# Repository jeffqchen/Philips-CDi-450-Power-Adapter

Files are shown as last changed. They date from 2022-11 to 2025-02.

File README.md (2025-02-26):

# Philips CD-i 450/550 Power Adapter

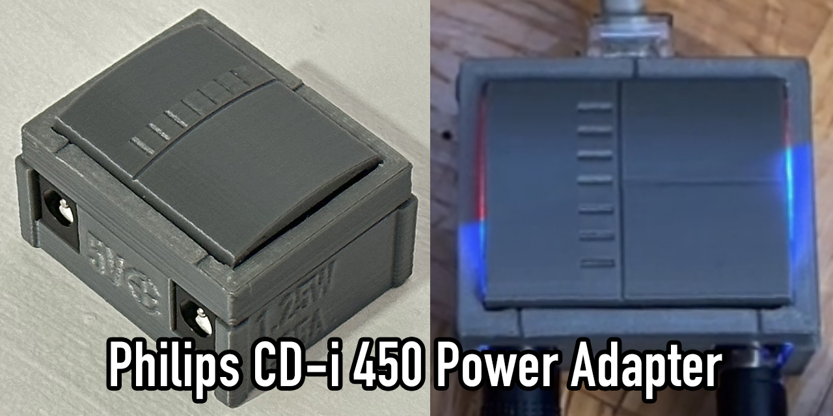
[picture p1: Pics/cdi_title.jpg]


------
## Update: Alternative Solution You Can Buy - G2 PSU



Zaxour designed a new replacement power supply that takes a single power input and converts it to all the necessary power rails. I had the honor to design a shell for it.

You can actually purchase the G2 PSU [here](https://ko-fi.com/s/8996431f0d).

------
## Rambling

The Philips CD-i 450/550 has a weird PSU (Type 20 PS 301/XX, 20PS301, 22ER9156). It uses an RJ45 jack to connect to the console.

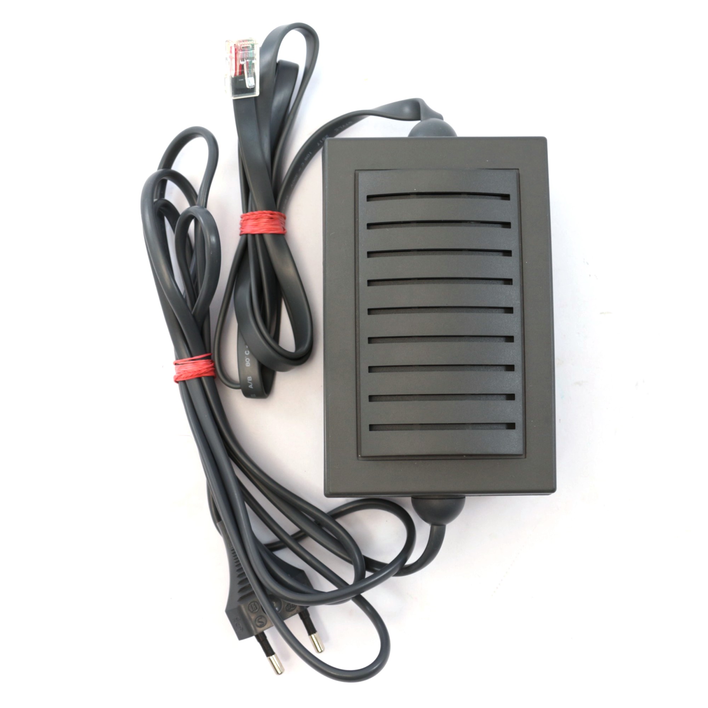
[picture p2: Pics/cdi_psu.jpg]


Everybody familiar with ethernet cables knows the plastic tab on an RJ45 plug will snap off sooner or later. Then the plug will become loose and start falling out of the jack. While it might not be that devastating on a network connection, it is unacceptable for a power connection. Not to mention that over the decades, some consoles were separated from their original PSU, and replacements are expensive while supplies being limited.

------
## Functionality

### Power Sources

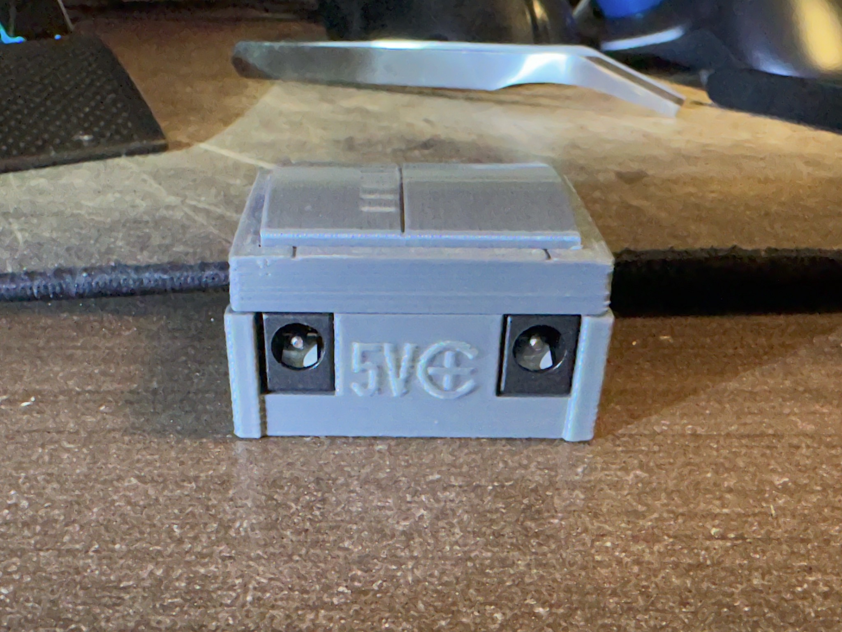
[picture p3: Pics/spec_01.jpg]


This adapter utilizes TWO **Center-Positive 5V** power adapters, with the plug dimension of **5.50mm OD (0.217") and 2.10mm ID (0.083")**.

**Do NOT** use a Y-adapter with a single power source or your adapter will short and die.

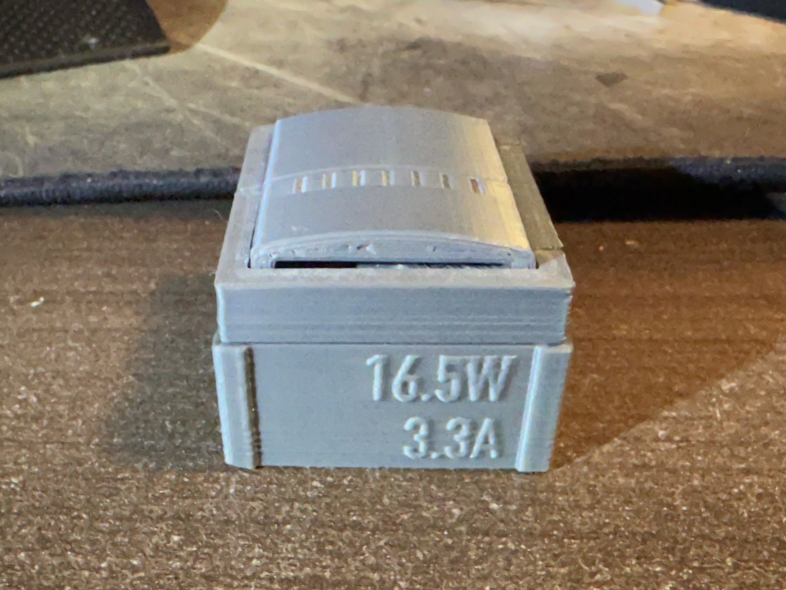
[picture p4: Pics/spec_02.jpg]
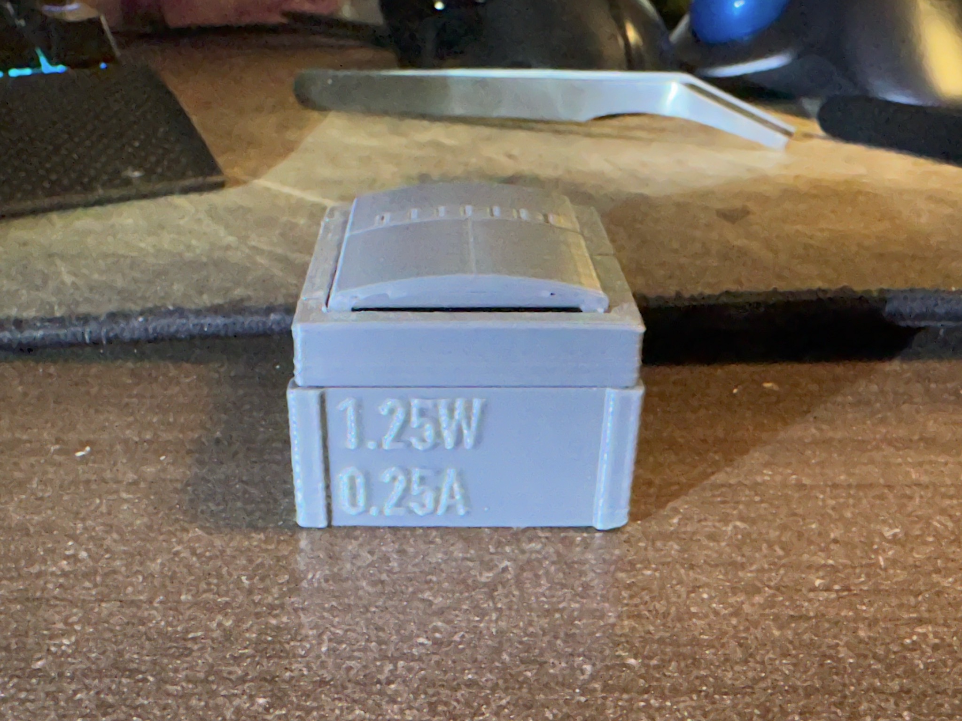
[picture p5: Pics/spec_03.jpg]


The one on the left requires 3.3A (16.5W). I call this the "beefy" one.

The one on the right is a weak one that any 5V adapter you can find will be more than capable to handle the job.

These power rating specs are the lowest requirements. You can go higher but not lower.

### Transmission Cable

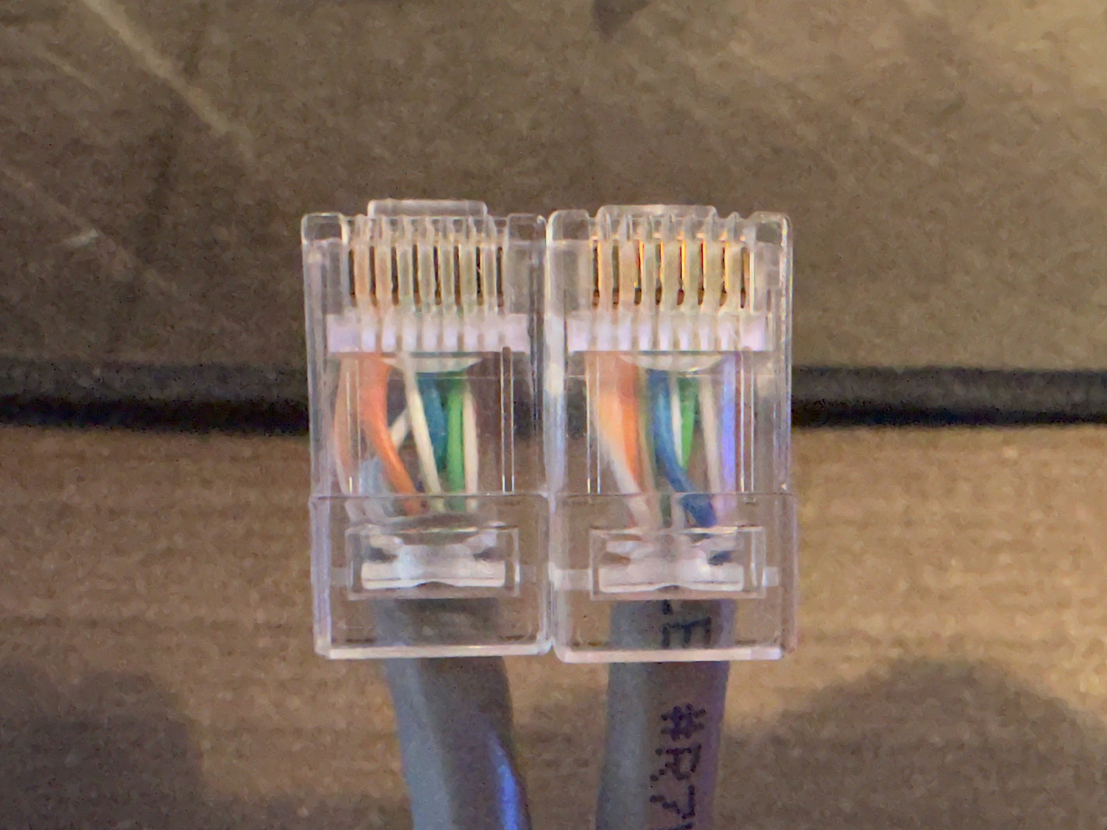
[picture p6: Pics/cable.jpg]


Use a **straight** RJ45 ethernet cable in short length. The wiring order on the two ends of the cable should be **exactly the same** or bad things will happen. It's easy to test with a meter if visual inspection is difficult.

### Usage

Plug everything in and use the power switch on the CD-i itself to turn the power on/off.

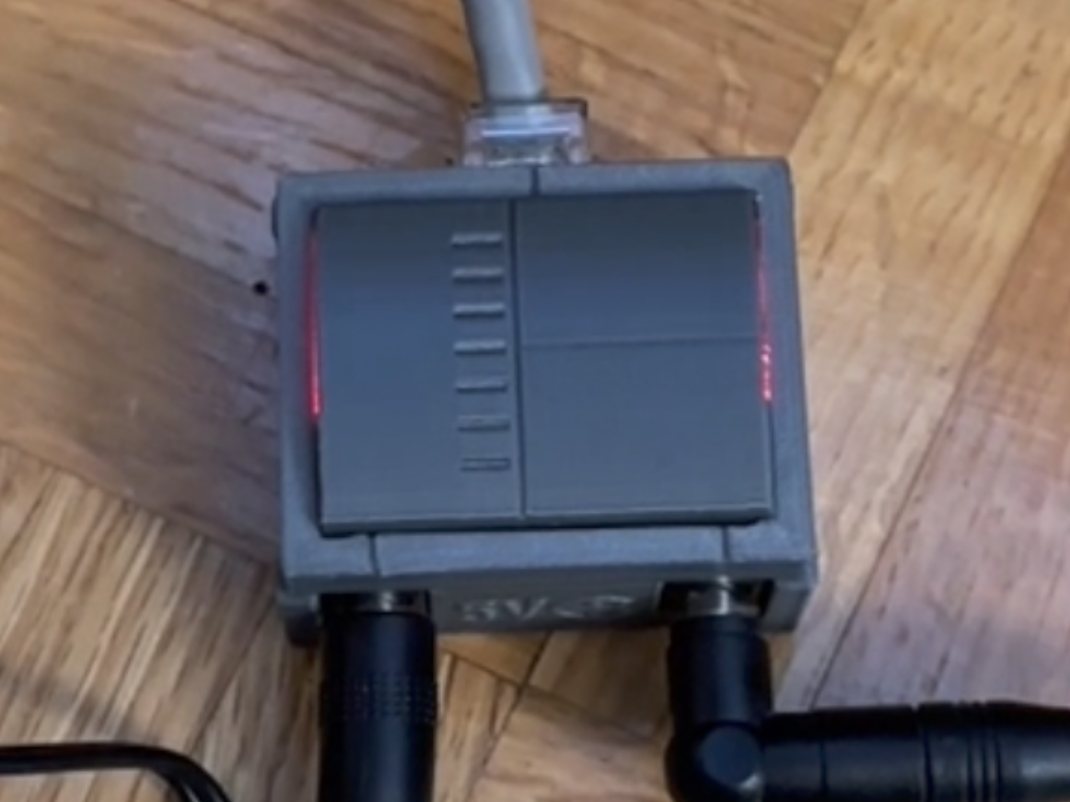
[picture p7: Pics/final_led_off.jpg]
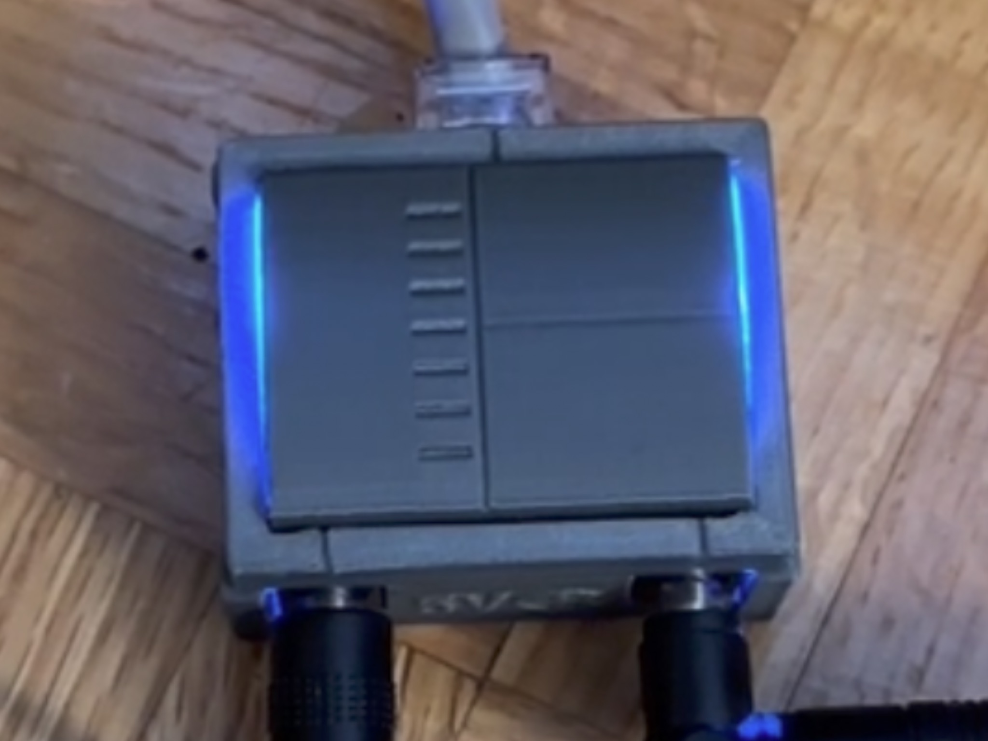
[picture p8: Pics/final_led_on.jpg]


------
## Parts
- PCB - [Link](https://oshpark.com/shared_projects/HBbJdevy)
- [2x] PJ-002A Barrel Jack, OD 5.50mm / ID 2.10mm - [Link](https://github.com/jeffqchen/JeffParts/blob/main/Connectors/Barrel%20Jack/PJ-002A/info.md)
- 1705951 RJ45 Ethernet Jack, Female - [Link](https://github.com/jeffqchen/JeffParts/blob/main/Connectors/RJ45/Female/1705951/info.md)
- J104A2C5VDC.40S General Purpose Relay, DPDT, 5V/3A - [Link](https://github.com/jeffqchen/JeffParts/blob/main/Components/J104A2C5VDC.40S%20Relay/info.md)
- M3x20mm hex screw and nut - [Link](https://github.com/jeffqchen/JeffParts/blob/main/Parts/M2%20M3%20Hex%20Screw%20%26%20Nut/info.md)
- 3D Printed Case - [Link](https://github.com/jeffqchen/Philips-CDi-450-Power-Adapter/tree/main/3D%20Print)

**Optional Parts**
- 1N4148W Diode, SMD - [Link](https://github.com/jeffqchen/JeffParts/blob/main/Components/1N4148W/info.md) (for possible extending lifespan of relay coil)
- LEDs for power state indication
  - Two of each color, with their respective current limiting resistor (0805 size or smaller)
  - Typical LED forward voltage range from 2V to 3.2V. 100-150 Ohm resistors is a good choice.

### Power Sources

- "Beefy" WSU050-4000, 5V/20W, OD5.5mm/ID2.1mm, Triad Power Adapter - [Link](https://github.com/jeffqchen/JeffParts/blob/main/Power/WSU050-4000/info.md)
- WSU050-1500, 5V/7.5W OD5.5mm/ID2.1mm, Triad Power Adapter - [Link](https://github.com/jeffqchen/JeffParts/blob/main/Power/WSU050-1500/info.md) (but really, any 5V adapter will do)

------
## 3D Printing The Shell

Print the parts as shown in the following pics, with support.

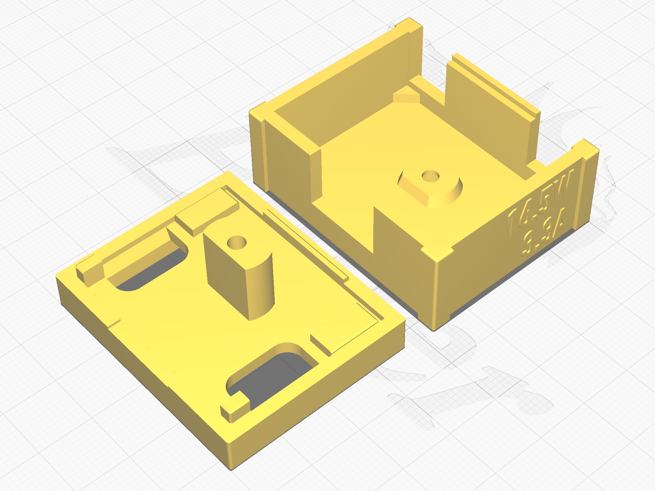
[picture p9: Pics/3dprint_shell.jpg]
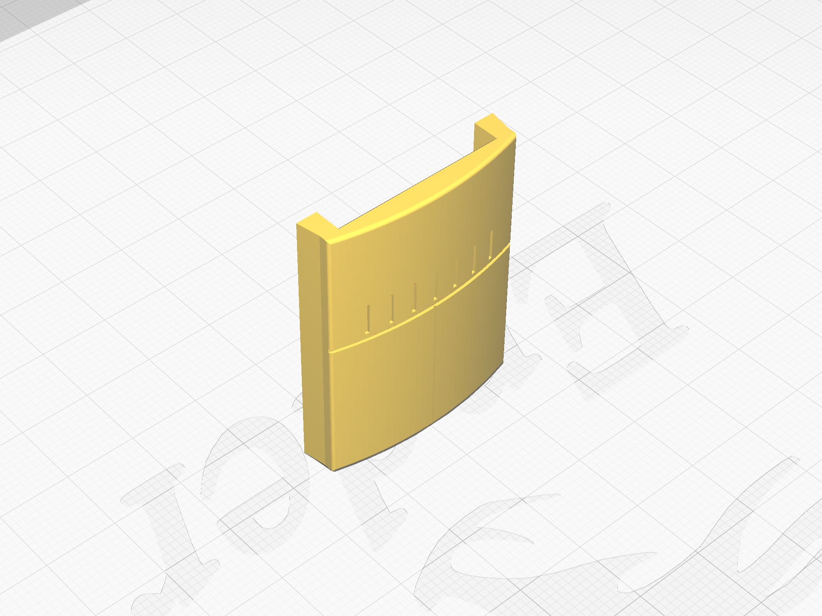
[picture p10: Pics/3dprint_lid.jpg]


------
## Assembly

### Populating Components

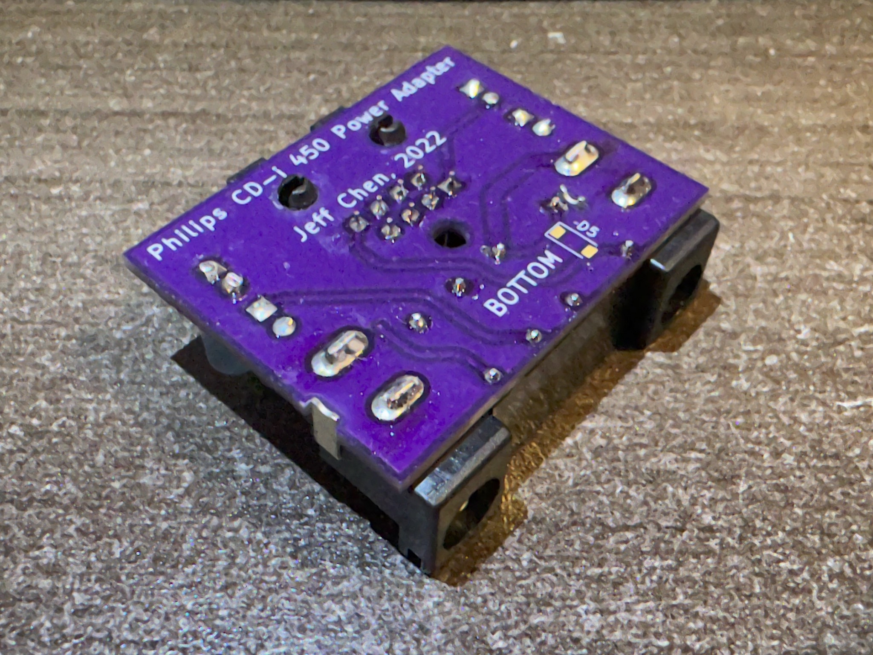
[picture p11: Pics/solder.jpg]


Populate the PCB with parts. Trim the extra length of extruding legs but no need to go crazy.

#### LEDs
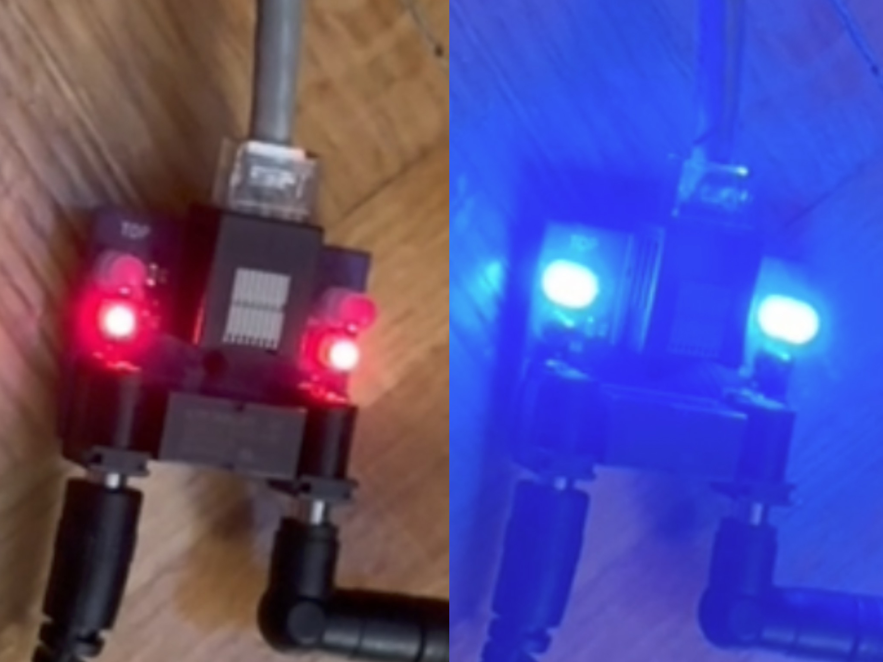
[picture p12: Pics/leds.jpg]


D1 and D2 are for standby and D3 and D4 are for running. Choose your colors accordingly.

If in case one side does not light up, please check your power sources first as there might be a serious problem.

### Closing The Case

Fit into the bottom shell. Close the top shell over.

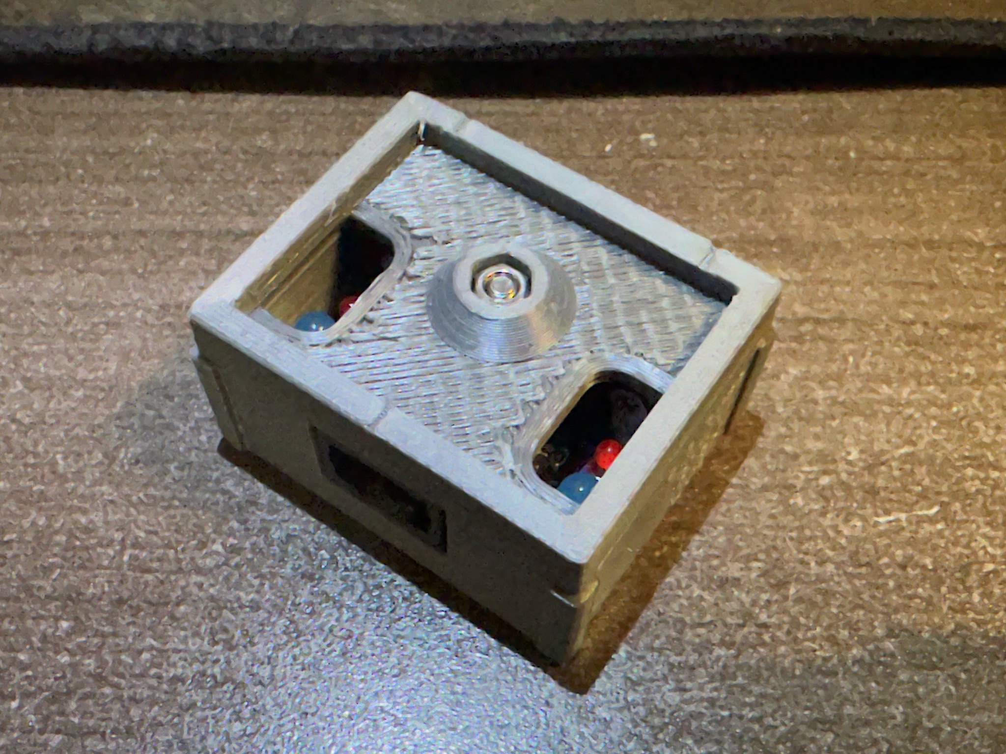
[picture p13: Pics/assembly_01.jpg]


Drop the nut inside the cavity, then tighten the screwn from the bottom.

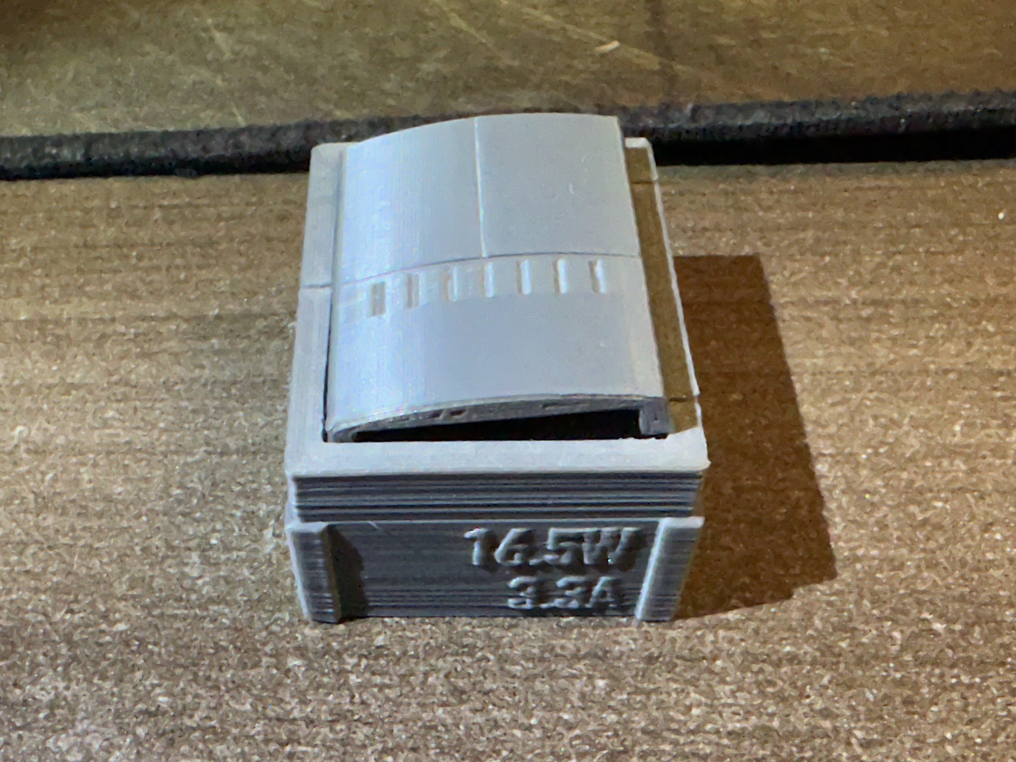
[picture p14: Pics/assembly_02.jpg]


Drop in the top lid inside, fit one side in position first, then press and snap the other side into the slot.

This concludes the assembly.

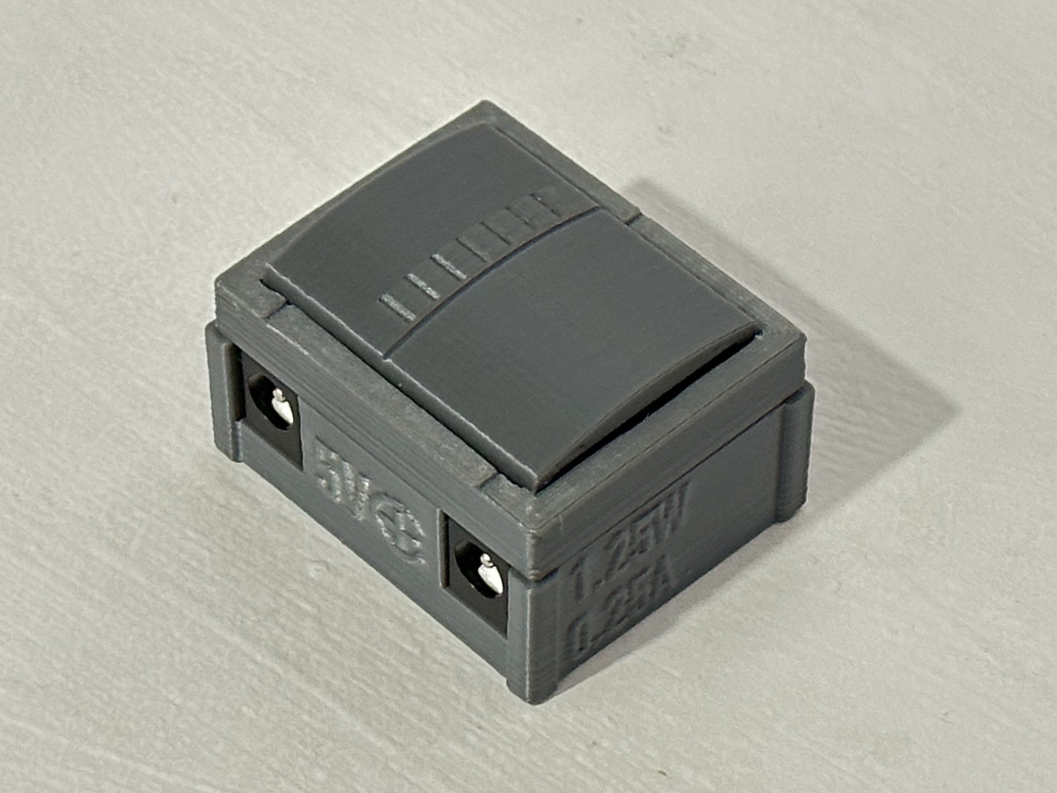
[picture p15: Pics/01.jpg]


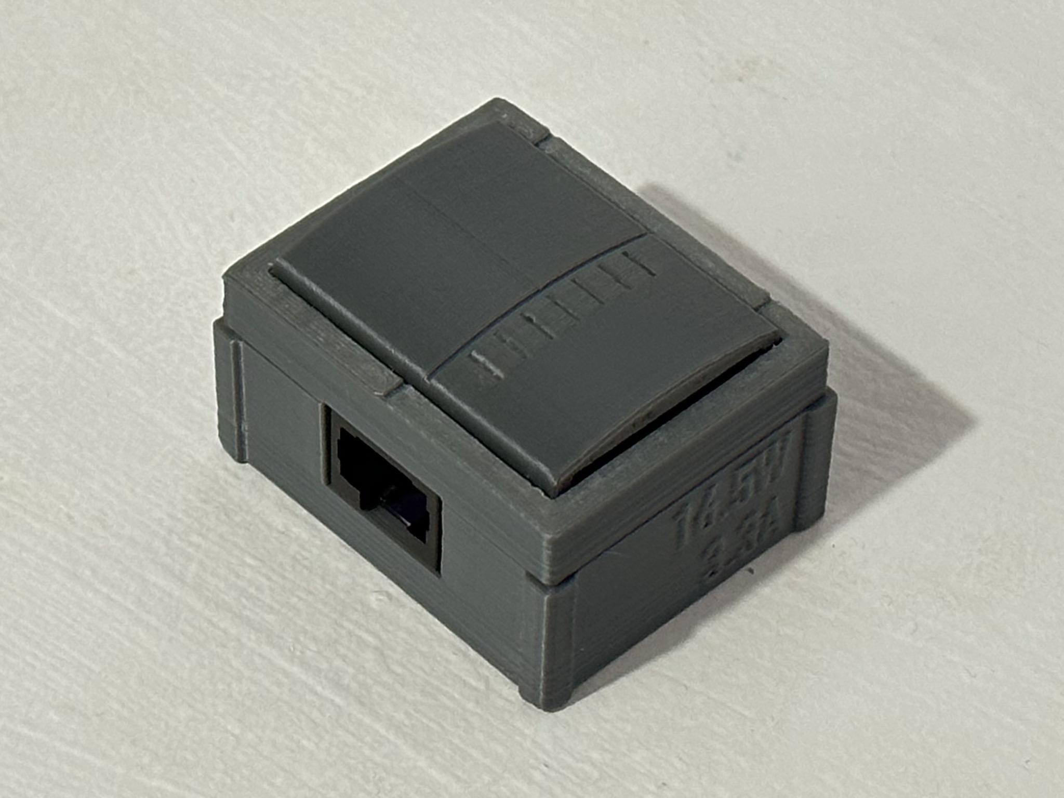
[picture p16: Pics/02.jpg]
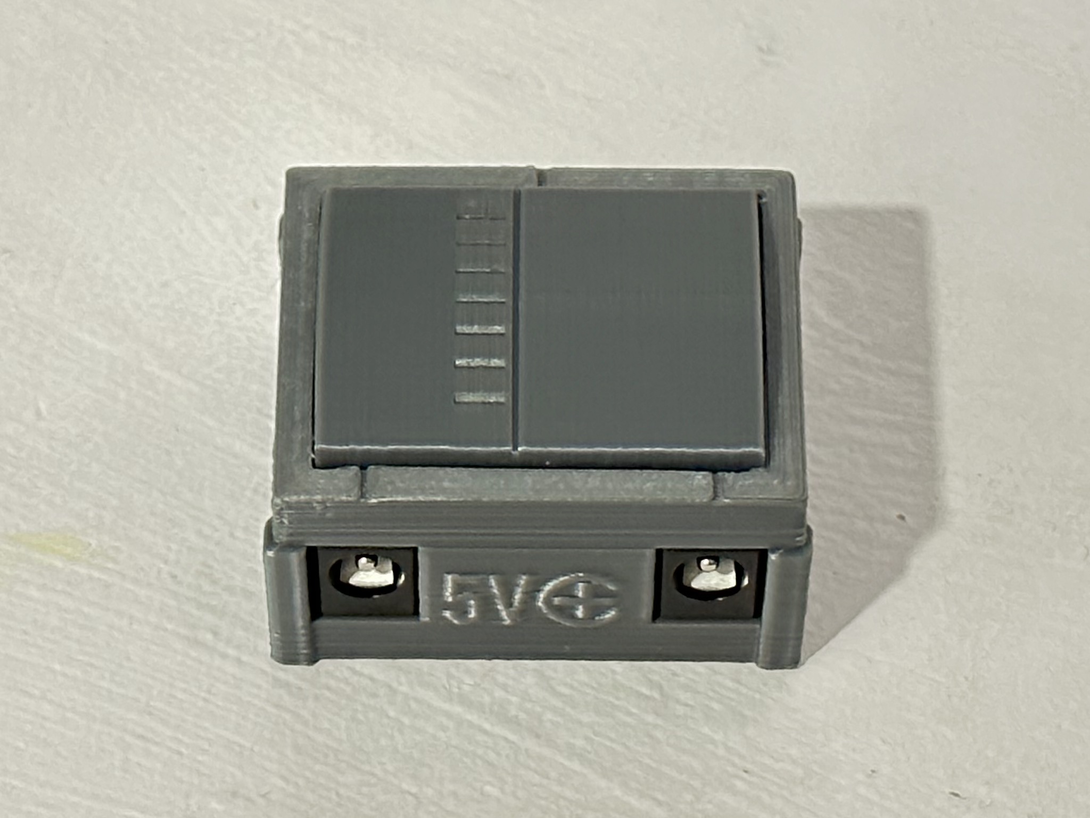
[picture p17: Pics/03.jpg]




------
## Special Thanks

- Retrostuff (for suggesting various technical details about the Philips CD-i)
  - [Twitter](https://twitter.com/retrostuff_org)
  - [Website](https://retrostuff.org/)

------
Shield: [][cc-by-sa]

This work is licensed under a
[Creative Commons Attribution-ShareAlike 4.0 International License][cc-by-sa].

[][cc-by-sa]

[cc-by-sa]: http://creativecommons.org/licenses/by-sa/4.0/
[cc-by-sa-image]: https://licensebuttons.net/l/by-sa/4.0/88x31.png
[cc-by-sa-shield]: https://img.shields.io/badge/License-CC%20BY--SA%204.0-lightgrey.svg

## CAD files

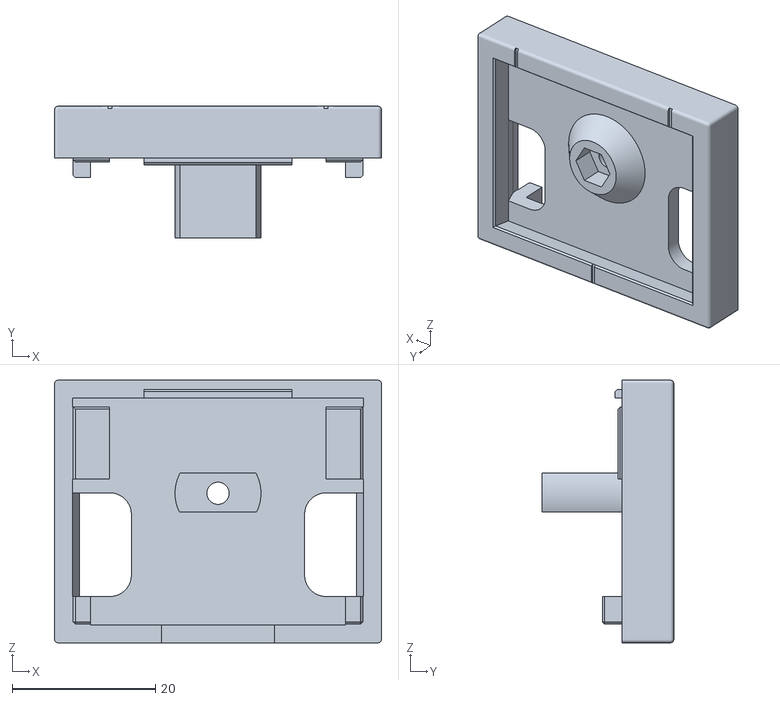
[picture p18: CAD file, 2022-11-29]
3D Print/Top Shell.stl
45.7 x 18.4 x 36.7

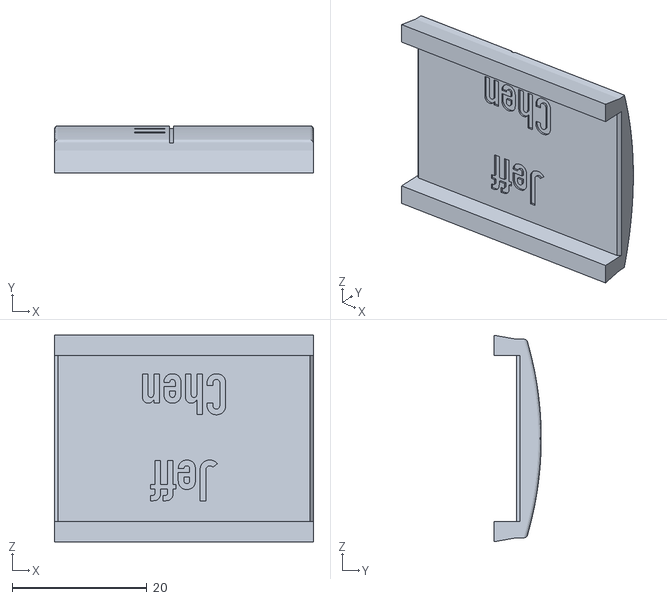
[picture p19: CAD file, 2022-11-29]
3D Print/Top Lid.stl
38.5 x 7.06 x 30.7

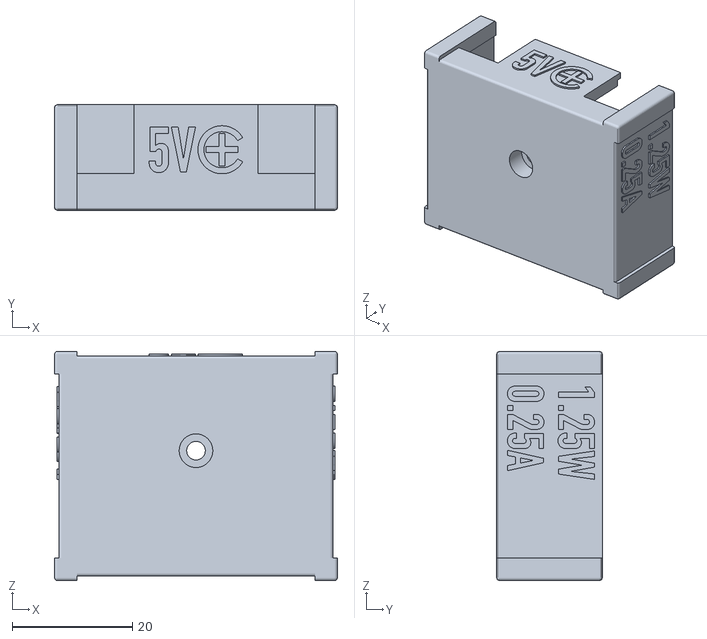
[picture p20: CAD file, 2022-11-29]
3D Print/Lower Shell.stl
47.1 x 17.6 x 38.2

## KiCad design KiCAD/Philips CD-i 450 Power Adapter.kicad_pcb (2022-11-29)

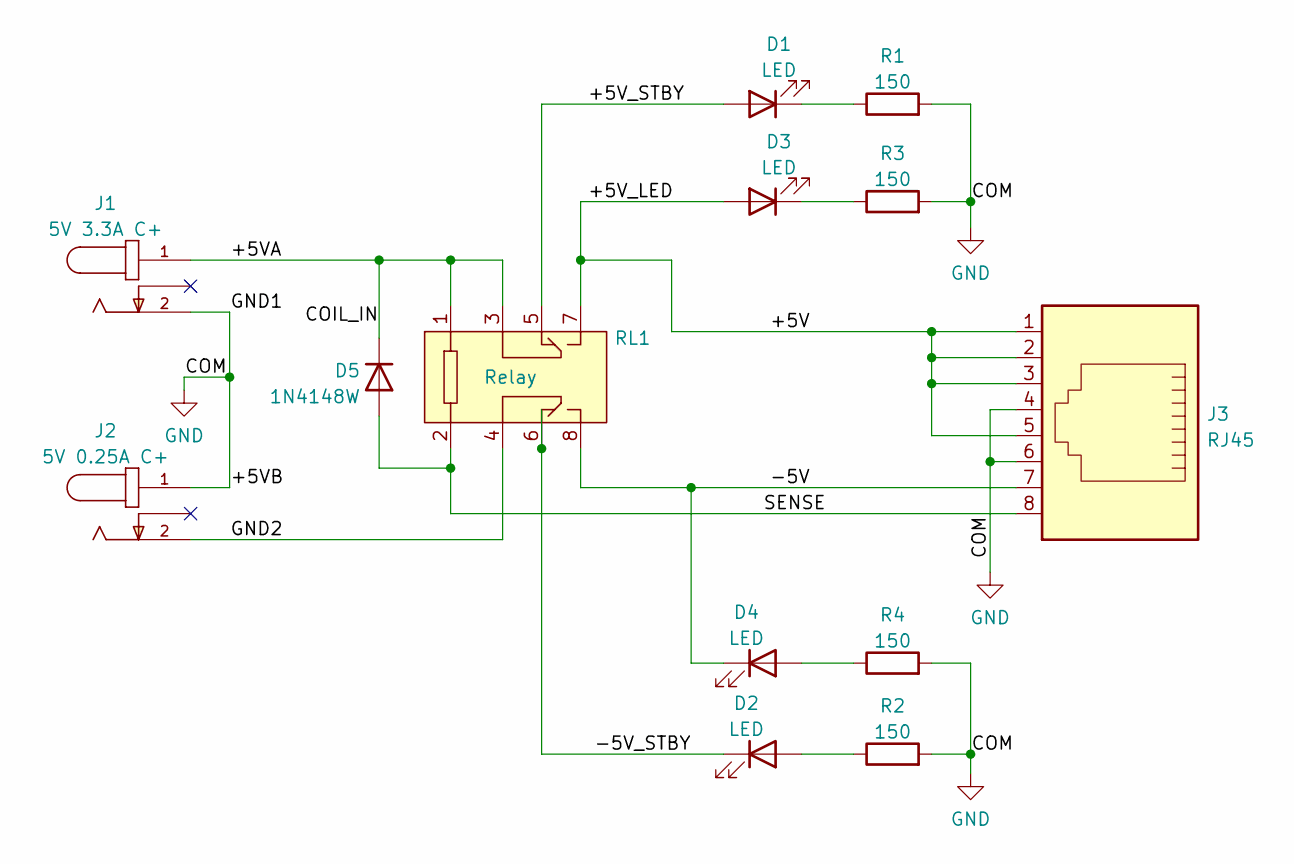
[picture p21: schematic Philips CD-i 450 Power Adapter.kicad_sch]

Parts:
D1, D2, D3, D4: LED; LED_D5.0mm
D5: 1N4148W; D_SOD-123
J1: 5V 3.3A C+; CUI_PJ-002A
J2: 5V 0.25A C+; CUI_PJ-002A
J3: RJ45
R1, R2, R3, R4: 150; R_0805_2012Metric_Pad1.20x1.40mm_HandSolder
RL1: Relay

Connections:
/+5V: D3.2 (A), J3.1, J3.2, J3.3, J3.5, RL1.7
/+5VA: D5.1 (K), J1.1, RL1.1, RL1.3
/+5V_STBY: D1.2 (A), RL1.5
/-5V: D4.1 (K), J3.7, RL1.8
/-5V_STBY: D2.1 (K), RL1.6
/GND2: J2.2, RL1.4
/SENSE: D5.2 (A), J3.8, RL1.2
GND: J1.2, J2.1, J3.4, J3.6, R1.2, R2.2, R3.2, R4.2
unnamed: D1.1 (K), R1.1
unnamed: D2.2 (A), R2.1
unnamed: D3.1 (K), R3.1
unnamed: D4.2 (A), R4.1

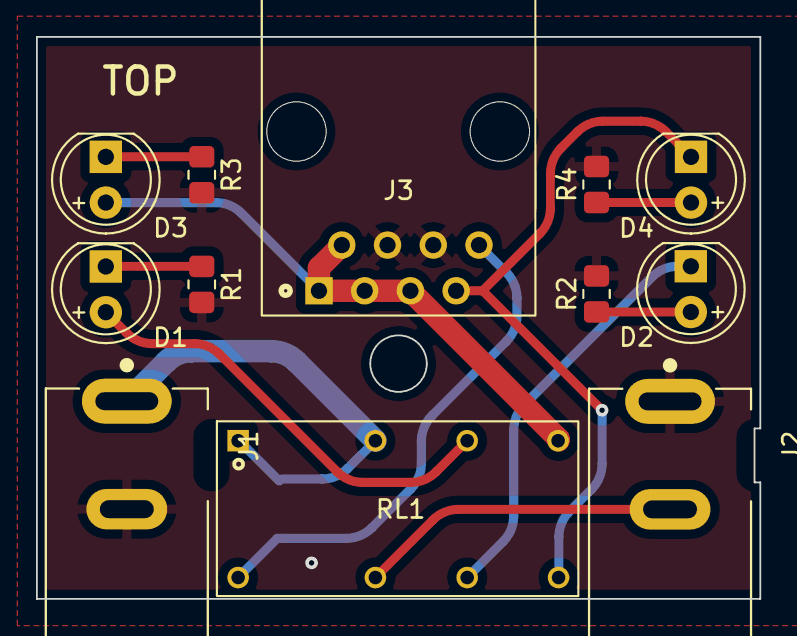
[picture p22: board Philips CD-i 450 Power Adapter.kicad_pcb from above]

Board: 2 copper layers, 40.2 x 31.2 mm, 13 parts (1 on the bottom side), 12 nets.

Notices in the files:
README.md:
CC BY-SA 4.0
